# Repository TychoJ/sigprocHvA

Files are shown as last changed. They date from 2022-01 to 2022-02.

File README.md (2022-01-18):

# sigprocHvA
## Ned
Voor een opdracht van de HvA moet een filter ontworpen worden. Dit is voor het tweedejaars vak signaalverwerking toepassing. Dit filter moet zowel analoog als digitaal ontworpen worden en hier moet een verslag voor worden geschreven in het Nederlands.
___
## ENG
For a lab from the Amsterdam University of Applied there needed be a filter designed. This filter needed to be implemented analog as wel as digitally. Afterwords a report has to be written in dutch for this lab.
___

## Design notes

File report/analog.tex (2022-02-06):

\section{Analoog}
\subsection{De opdracht}
\begin{minipage}{0.45\textwidth}
	Maak een derde orde 0.5dB ripple chebyshev lowpass filter met een $F_C$ van 70Hz. In de doorlaat band 
	moet er met 10dB worden versterkt. Uit de tabel zijn de volgende gegevens te halen.

	\noindent
	Daarnaast moet het filter met de Sallen-key topologie worden gerealiseerd.
\end{minipage}
\hfill
\begin{minipage}{0.45\textwidth}
	\begin{itemize}
		\item In doorlaat +10dB versterking
		\item $\omega_{0_1}=1.0688$ 
		\item $\omega_{0_2}=0.6265$
		\item $\alpha = 0.5861$
		\item $Q=\frac{1}{\alpha}=1.7061$
	\end{itemize} % Gegevens komen uit tabel 8.30 van het boek linear circuit design
\end{minipage}

\subsection{Overdracht bepalen}
\begin{minipage}{0.40\textwidth}
	Door de waardes uit de tabel in te vullen in de standaard formule (zie formule \ref{eq:hs})
	komt daar formule \ref{eq:hsNum} uit.

	\noindent
	H(s) kan worden opgesplitst in een tweede orde deel en een eerste orde deel zie formule \ref{eq:hsSplit}.
	Het opsplitsen van $H(s)$ in $H(s)_1$ en $H(s)_2$ is noodzakelijk voor het goed ontwerpen van het analoge 
	filter.

	\noindent
	Het tweede orde deel heeft de overdracht die te zien is in formule \ref{eq:hs1} en de overdracht van
	het eerste orde	deel is te zien in formule \ref{eq:hs2}
\end{minipage}
\hfill
\begin{minipage}{0.60\textwidth}
	\begin{align}
		H(s)&=\frac{(\omega_{0_1}\cdot\omega_c)^2\cdot\omega_c\cdot\omega_{0_2}}{(s^2+ \alpha \cdot \omega_{0_1} \cdot \omega_c \cdot s + (\omega_{0_1}\cdot\omega_c)^2)\cdot (s + \omega_c \cdot \omega_{0_2})} \label{eq:hs} \\
		H(s)&=\frac{220\, 156.6429\,\cdot\, 275.0335}{(s^2+274.9999\cdot s+220\, 156.6429)(s+275.0335)} \label{eq:hsNum}\\
		H(s)&= H(s)_1 \cdot H(s)_2 \label{eq:hsSplit} \\ 
		H(s)&_1=\frac{(\omega_{0_1}\cdot\omega_c)^2}{s^2+ \alpha \cdot \omega_{0_1} \cdot \omega_c \cdot s + (\omega_{0_1}\cdot\omega_c)^2} \label{eq:hs1} \\ 
		H(s)&_2=\frac{\omega_c\cdot\omega_{0_2}}{s + \omega_c \cdot \omega_{0_2}} \label{eq:hs2} \\ 
	\end{align}
\end{minipage}
 
%$H(s)_1=\frac{220\, 156.6429}{s^2+274.9999s+220\, 156.6429}$
%$H(s)_2=\frac{275.0335}{s+275.0335}$

\subsection{Tweede orde/Sallen-key}
\begin{wrapfigure}[6]{l}{0.25 \textwidth}
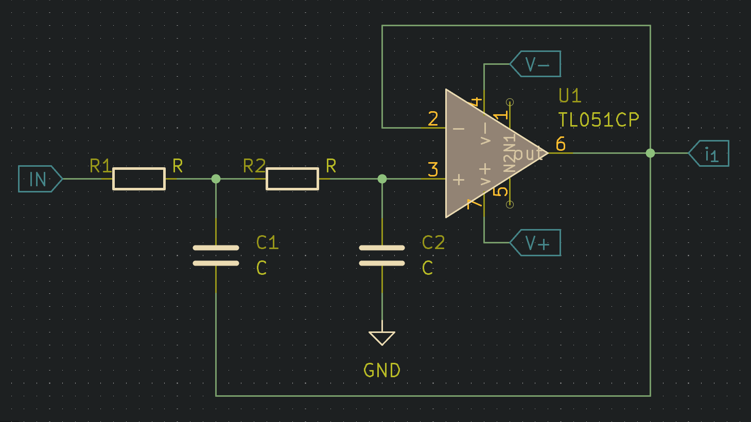
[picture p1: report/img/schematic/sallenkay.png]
	
	\caption{Sallen-key}
	\label{fig:sallenKey}
\end{wrapfigure}

\vphantom{-}\\
\begin{minipage}{0.37\textwidth}
	Het tweede orde deel van het derde orde filter wordt via de Sallen-key topologie gerealiseerd. In afbeelding \ref{fig:sallenKey} is te zien 
	hoe een laag doorlaat sallen-key filter er uit ziet.
\end{minipage}
\hfill
\begin{minipage}{0.37\textwidth}
	\begin{equation} \label{eq:c1}
		C_1=\frac{2Q}{\omega_c\omega_{0_1}R}
	\end{equation}
	\begin{equation} \label{eq:c2}
		C_2=\frac{1}{2Q\omega_c\omega_{0_1}R}
	\end{equation}
\end{minipage}
\vphantom{-}\\

\noindent
Als $R_1 = R_2$ kan $C_1$ berekend worden met formule \ref{eq:c1} en $C_2$ met formule \ref{eq:c2}.
Voor dit filter is gekozen om voor R $10k\Omega$ te kiezen. Waardoor $C_1=727nF$.

\noindent
727nF is alleen niet een waarde waarin condensatoren worden gemaakt. Door $C_1$ te veranderen naar 750nF 
kan er wel een condensator worden gekocht met de juiste waarde. 

\noindent
Door $C_2$ met formule \ref{eq:c2} uit te rekenen komt $C_2$ uit op een waarde van 62nF, deze waarde is wel direct 
te koop. 

\noindent
Beide waardes zitten alleen niet in de E6/12 reeks en zijn dus aanzienlijk duurder, 
hier gaat een afweging meespelen tussen de prijs van componenten en de kwaliteit van het filter.

\subsection{Eerste orde}
\begin{wrapfigure}[6]{l}{0.25\textwidth}
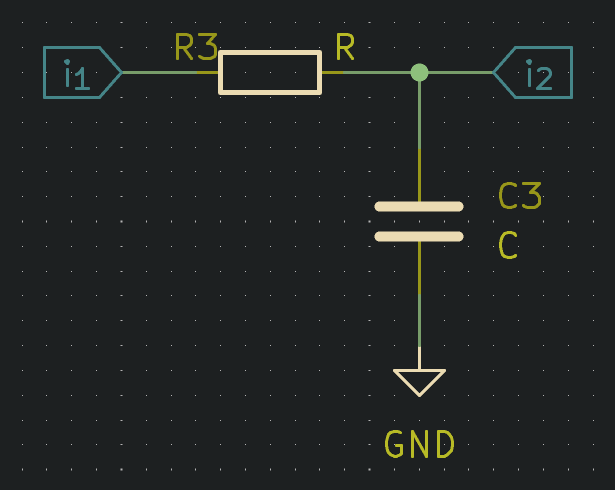
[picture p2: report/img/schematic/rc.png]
	
	\caption{Eerste orde lp filter}
	\label{fig:lp}
\end{wrapfigure}
\vphantom{-}\\
Een passief eerste orde laag doorlaat filter staat in figuur \ref{fig:lp}. Met formule \ref{eq:rc} is het mogelijk om de verschillende component waardes uit te rekenen 
voor het filter. Wij hebben $C_3=100nF$ gekozen waaruit formule \ref{eq:rcValR} volgt dat 
$R_3=5787\Omega$ dit moet worden afgerond op $5.6k\Omega$ omdat er geen weerstanden beschikbaar zijn met een waarde van $5787\Omega$.

\begin{flushright}
	\begin{minipage}{0.37\textwidth}
		\begin{equation} \label{eq:rc}
			\omega_c*\omega_{0_2}=\frac{1}{R_3C_3}
		\end{equation}
	\end{minipage}
	\begin{minipage}{0.37\textwidth}
		\begin{equation} \label{eq:rcValR}
			R_3=\frac{1}{\omega_c\omega_{0_2}C_3}
		\end{equation}
	\end{minipage}
\end{flushright}
\newpage

\subsection{LTspice}
Het filter dat in afbeelding \ref{fig:filterTotaal} is te zien is gesimuleerd in LTspice. De resultaten van de simulatie zijn te zien
in afbeelding \ref{fig:simRes}.
\begin{figure}[!htb]
	\begin{minipage}{0.45\textwidth}
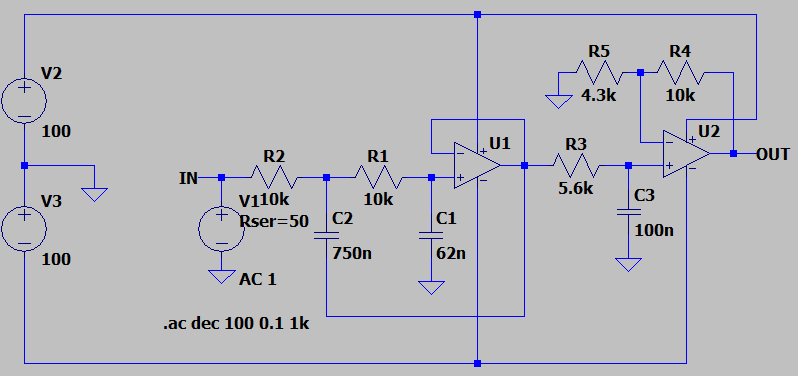
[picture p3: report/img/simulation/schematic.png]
		
		\caption{Eerste orde lp filter}
		\label{fig:filterTotaal}
	\end{minipage}
	\begin{minipage}{0.45\textwidth}
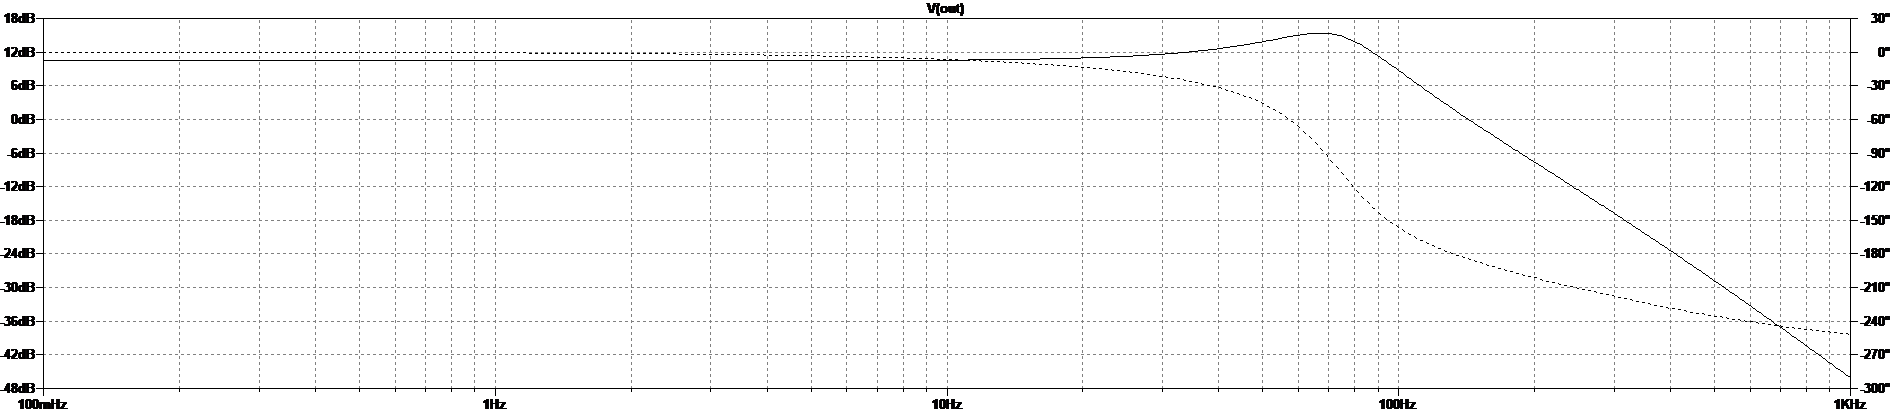
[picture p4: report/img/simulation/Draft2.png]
		
		\caption{LTspice simulatie}
		\label{fig:simRes}
	\end{minipage}
\end{figure}

\subsection{PCB}
	\begin{wrapfigure}[5]{r}{0.25\textwidth}
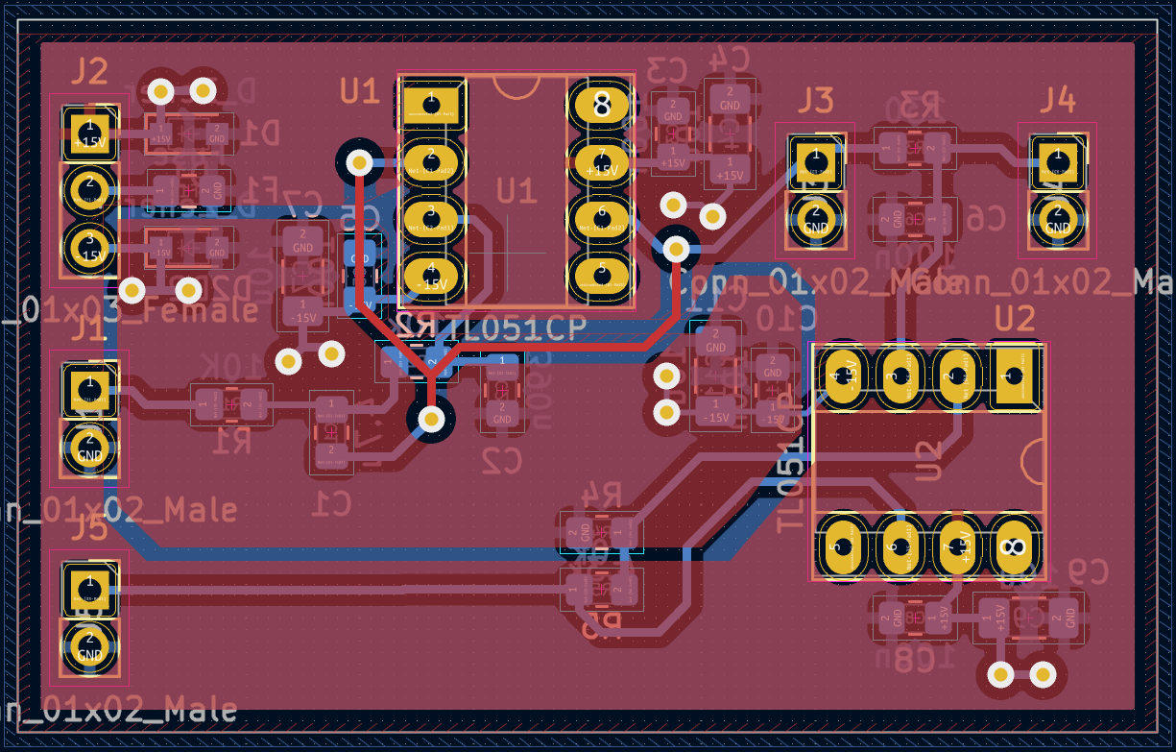
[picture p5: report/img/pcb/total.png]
		
		\caption{Layout}
		\label{fig:pcb:layout}
	\end{wrapfigure}
	Voor deze opdracht hebben wij een pcb ontworpen, op afbeelding \ref{fig:pcb:layout} is de layout te zien. Wij hebben er voor gekozen om een pcb te makenom de 
	parasitaire eigenschappen van onder anderen het breadboard tegen te gaan.

	\noindent
	Bij de layout zijn er nog wel een paar dingen die verbeterd zouden kunnen worden. Een voorbeeld is te zien in afbeelding \ref{fig:pcb:verbeter}
	en in afbeelding \ref{fig:pcb:verbeterde} is te zien hoe dit valt te verbeteren. 
	\begin{figure}[!htb]
		\begin{subfigure}[b]{0.33\textwidth}
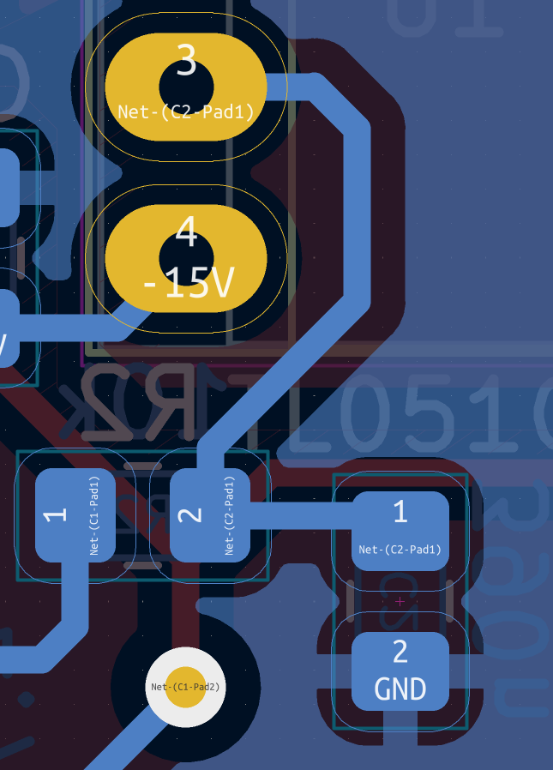
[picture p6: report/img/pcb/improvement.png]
			
			\caption{Dit kan worden verbeterd}
			\label{fig:pcb:verbeter}
		\end{subfigure}
		\begin{subfigure}[b]{0.33\textwidth}
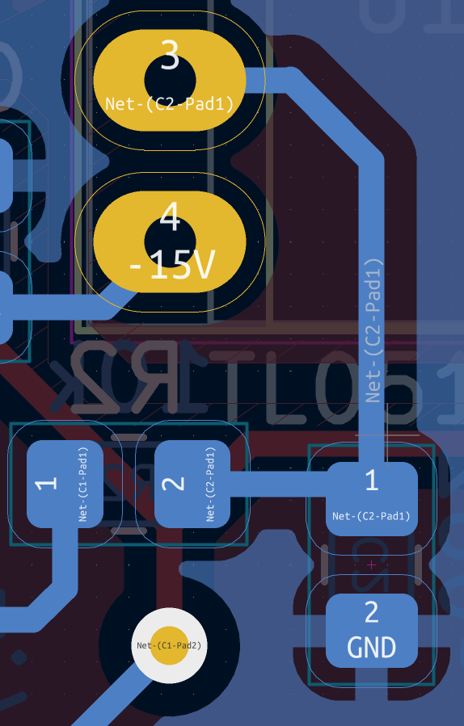
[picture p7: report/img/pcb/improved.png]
			
			\caption{Verbeterd}
			\label{fig:pcb:verbeterde}
		\end{subfigure}
		\caption{verbeter punt}
	\end{figure}

	\noindent
	Op afbeeldingen \ref{fig:pcb:3dBottom} en \ref{fig:pcb:3dTop} is een 3D render te zien van het gemaakte pcb. Bij het ontwerpen van dit pcb is 
	rekening gehouden met alle connectoren aan een kan van de print houden. Daarnaast zijn er nog een paar extra testpoints geplaatst om het debuggen
	van de schakeling makkelijker te maken als deze niet zou werken.
	\begin{figure}[!htb]
		\centering
		\begin{subfigure}[b]{0.45\textwidth}
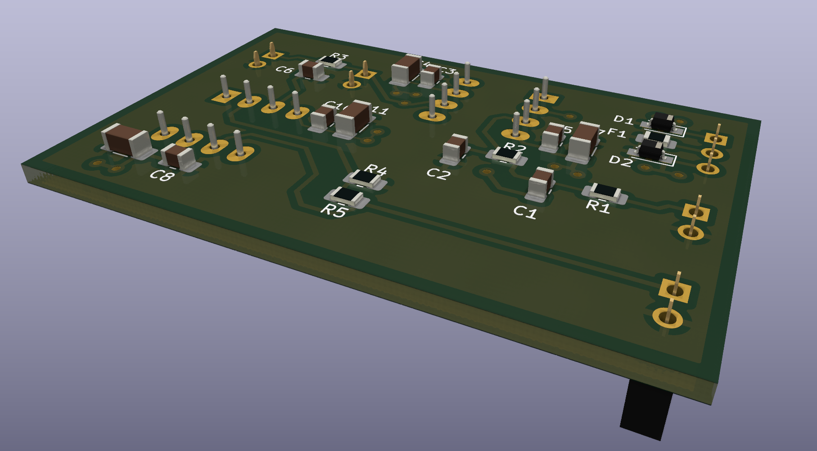
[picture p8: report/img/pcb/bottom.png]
			
			\caption{onderkant}
			\label{fig:pcb:3dBottom}
		\end{subfigure}
		\begin{subfigure}[b]{0.45\textwidth}
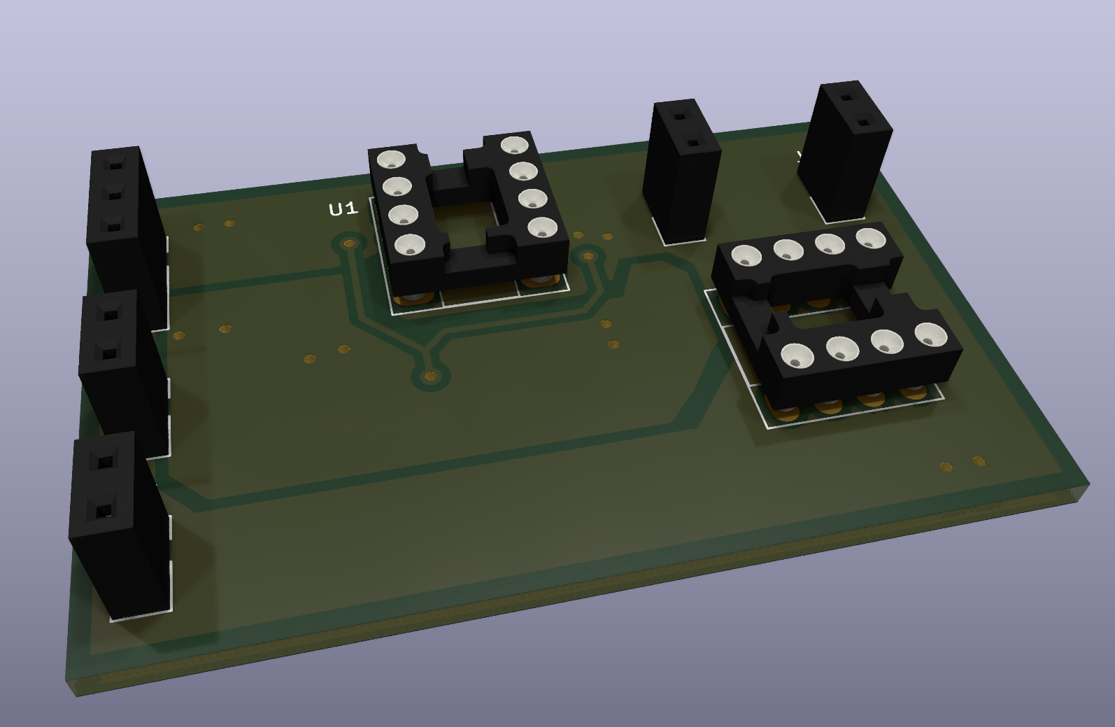
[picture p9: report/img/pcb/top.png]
			
			\caption{bovenkant}
			\label{fig:pcb:3dTop}
		\end{subfigure}
		\caption{3D renders}
	\end{figure}
	
\newpage

\subsection{Metingen}
\textbf{DISCLAIMER:} Tijdens het berekenen van het filter waren er wat reken fouten gemaakt waardoor het uiteindelijke ontwerp 
niet is opgebouwd met de correcte component waardes zoals ze in dit verslag staan. Het pcb is opgebouwd met de volgende waardes voor de componenten

\noindent
$R_1=R_2=10k\Omega$, $C_1=7.7uF$, $C_2=390nF$, $R_3=230\Omega$, $R_4=4.3k\Omega$ en $R_5=10k\Omega$
\\ 

\noindent
Bij alle metingen is er $\pm 10V$ geleverd ten opzichte van GND. Bij een ingangssignaal van 10Hz $1V_{PP}$ is op afbeelding \ref{fig:amp} te zien wat de output is.
Met een ingangssignaal van 70Hz $1V_{PP}$ is op afbeelding \ref{fig:atten} te zien wat de output is
\begin{figure}[!hbt]
	\begin{subfigure}{0.5\textwidth}
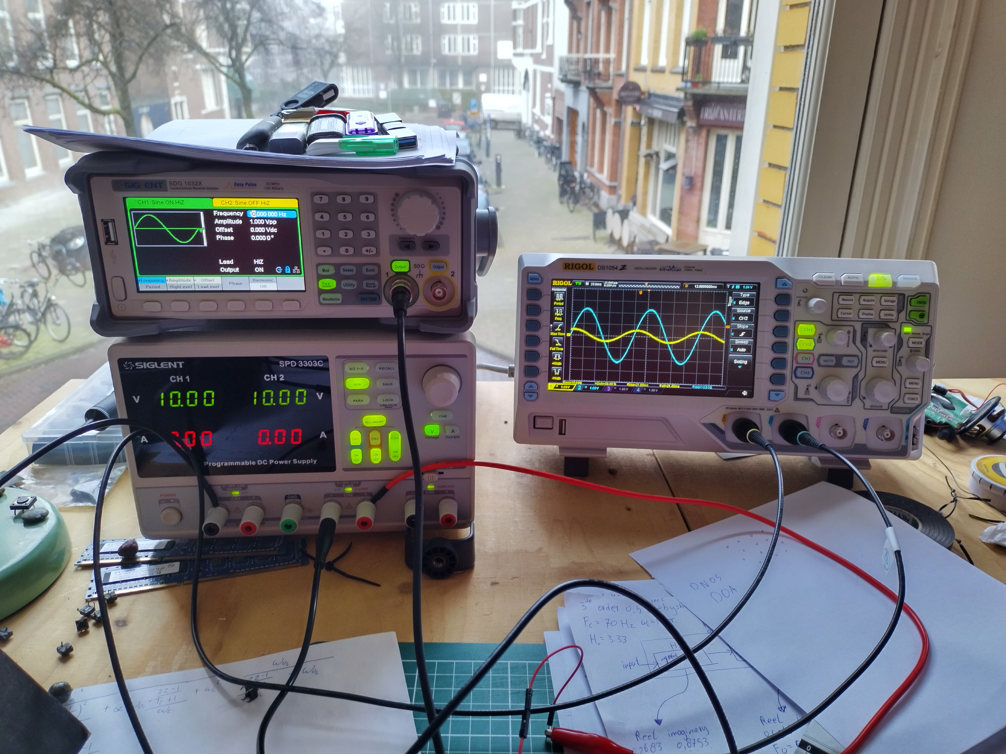
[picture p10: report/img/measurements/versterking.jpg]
		
		\caption{Versterking}
		\label{fig:amp}
	\end{subfigure}
	\begin{subfigure}{0.5\textwidth}
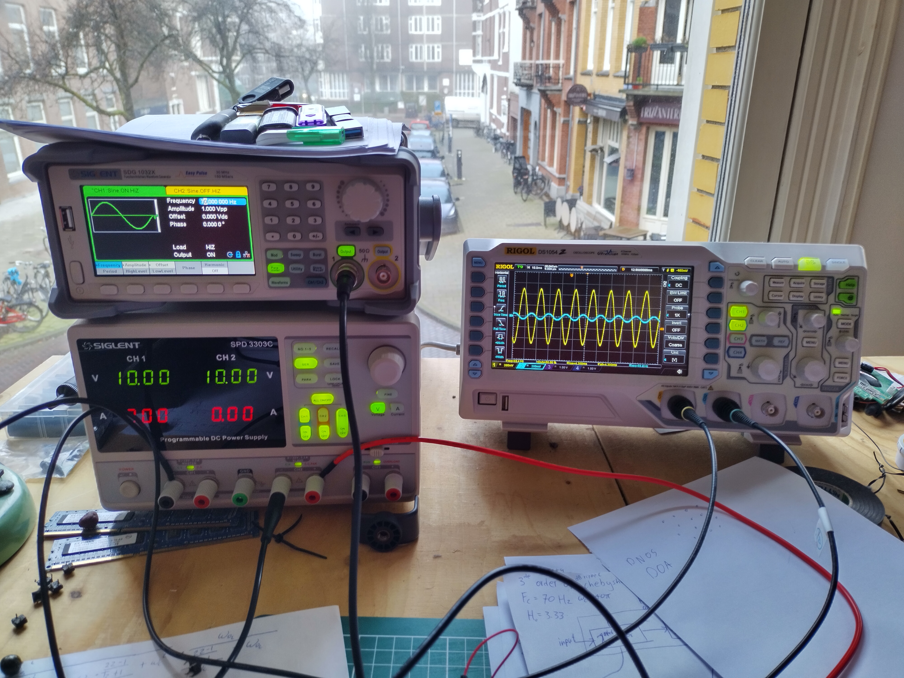
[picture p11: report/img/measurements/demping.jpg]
		
		\caption{Demping}
		\label{fig:atten}
	\end{subfigure}
	\caption{Meetingen met een oscilloscope}
\end{figure}

\noindent
Het is te zien dat in de doorlaat band het filter met ongeveer 10dB versterkt en in de stopband het signaal dempt. Waar exact het -3dB punt ligt is 
lichtelijk verschoven naar een lagere frequentie. Dit komt zoals in de disclaimer van dit stuk al staat er met verkeerde component waardes is gemeten.

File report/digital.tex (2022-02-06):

\section{Het digitale filter}

Met het MATLAB bestand voor een 1dB Chebychev filter hebben we een code geschreven voor het filter. 
Op het begin van de code worden alle waardes berekend in defines.
Deze waardes worden vervolgens gebruikt in de ISR van de ADC. De code is gebaseerd op de tekening in MATLAB.

\begin{figure}[!h]
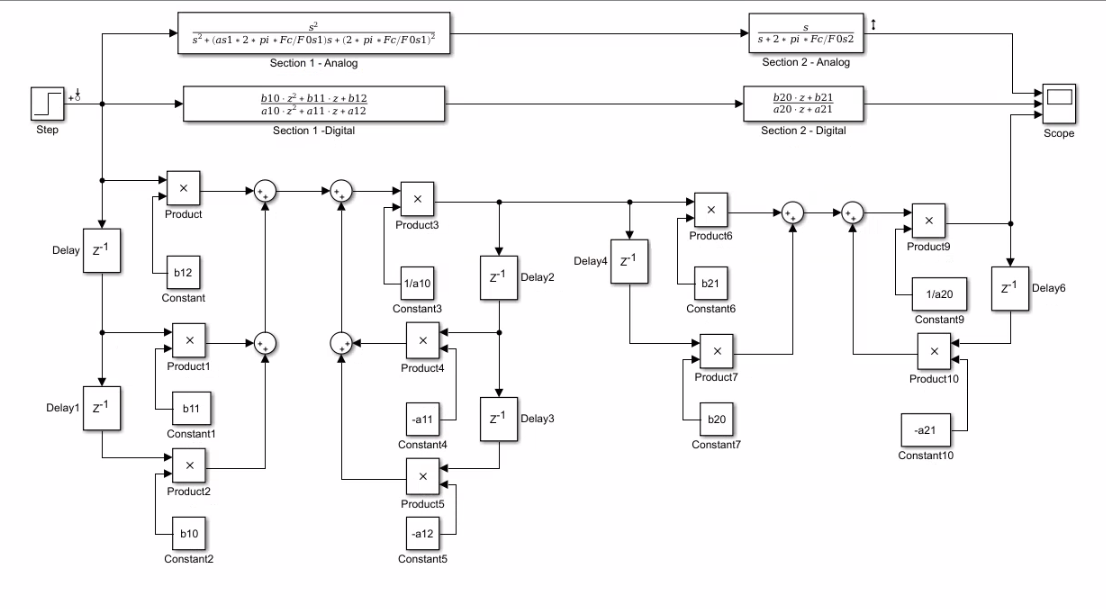
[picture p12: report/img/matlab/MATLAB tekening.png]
    
	\caption{Tekening in MATLAB}
	\label{fig:matlabDrawing}
\end{figure}

Het digitale filter is op dit moment niet functioneel.

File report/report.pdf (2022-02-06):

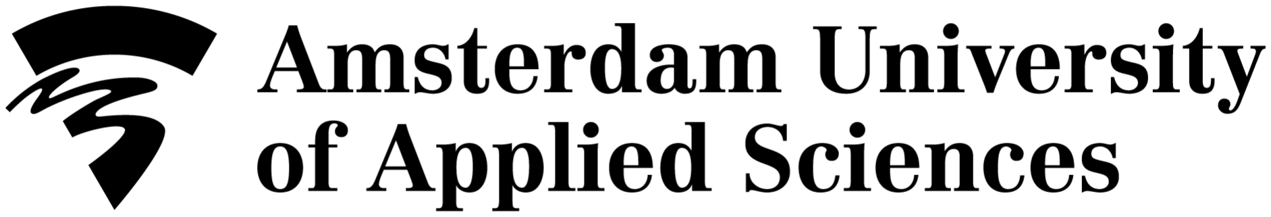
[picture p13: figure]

## Signaal verwerking toepassing

# derde orde 0.5dB chebyshev lp filter

Auteur(s): Tycho J¨obsis en Jochem Leijenhorst

Datum: 6 februari 2022 derde orde 0.5dB chebyshev lp filter

## Inhoudsopgave

1 Analoog | 2
INHOUDSOPGAVE | 1

derde orde 0.5dB chebyshev lp filter

## 1 Analoog

### 1.1 De opdracht

Maak een derde orde 0.5dB ripple chebyshev lowpass filter met een FC van 70Hz. In de doorlaat band moet er met 10dB worden versterkt. Uit de tabel zijn de volgende gegevens te halen.

| In doorlaat +10dB versterking
| ω01 = 1.0688
| ω02 = 0.6265
| α = 0.5861
| Q =
| 1 α = 1.7061

### 1.2 Overdracht bepalen

Door de waardes uit de tabel in te vullen in de standaard formule (zie formule 1) komt daar formule 2 uit.
H(s) kan worden opgesplitst in een tweede orde deel en een eerste orde deel zie formule 3. Het opsplitsen van H(s) in H(s)1 en H(s)2 is noodzakelijk voor het goed ontwerpen van het analoge filter.
Het tweede orde deel heeft de overdracht die te zien is in formule 4 en de overdracht van het eerste orde deel is te zien in formule 5
H(s) = | (ω01
- ωc)

2
- ωc · ω02
(s

2 + α · ω01
- ωc · s + (ω01
- ωc)
2) · (s + ωc · ω02
)

(1)

H(s) = | 220 156.6429 · 275.0335
(s
2 + 274.9999 · s + 220 156.6429)(s + 275.0335) | (2)
H(s) = H(s)1 · H(s)2 | (3)

H(s)1 =

(ω01

- ωc)

2
s

2 + α · ω01
- ωc · s + (ω01
- ωc)

2

(4)

H(s)2 =

ωc · ω02
s + ωc · ω02

(5)

(6)

### 1.3 Tweede orde/Sallen-key

Figuur 1: Sallen-key

Het tweede orde deel van het derde orde filter wordt via de Sallen-key topologie gerealiseerd. In afbeelding 1 is te zien hoe een laag doorlaat sallen-key filter er uit ziet.

C1 =

2Q
ωcω01R

(7)

C2 =

1
2Qωcω01R

(8)

Als R1 = R2 kan C1 berekend worden met formule 7 en C2 met formule 8. Voor dit filter is gekozen om voor R 10kΩ te kiezen. Waardoor C1 = 727nF.
727nF is alleen niet een waarde waarin condensatoren worden gemaakt. Door C1 te veranderen naar 750nF kan er wel een condensator worden gekocht met de juiste waarde.
Door C2 met formule 8 uit te rekenen komt C2 uit op een waarde van 62nF, deze waarde is wel direct te koop.
Beide waardes zitten alleen niet in de E6/12 reeks en zijn dus aanzienlijk duurder, hier gaat een afweging meespelen tussen de prijs van componenten en de kwaliteit van het filter.

### 1.4 Eerste orde

### 1.5 LTspice

### 1.6 Metingen

2

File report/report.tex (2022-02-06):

\documentclass[10pt, a4paper]{article}

\usepackage[dutch]{babel} 
\usepackage{hvaTemplate}
\usepackage{wrapfig}
\usepackage{caption}
\usepackage{subcaption}

\setAuthor{Tycho Jöbsis en Jochem Leijenhorst}
\extraInfo{Signaal verwerking toepassing}
\setTitle{derde orde 0.5dB chebyshev lp filter}

\graphicspath{ {img/} }

\begin{document}
\makeTitlepage
\newpage
\tableofcontents
\newpage
\include{analog.tex}
\include{digital.tex}
\end{document}

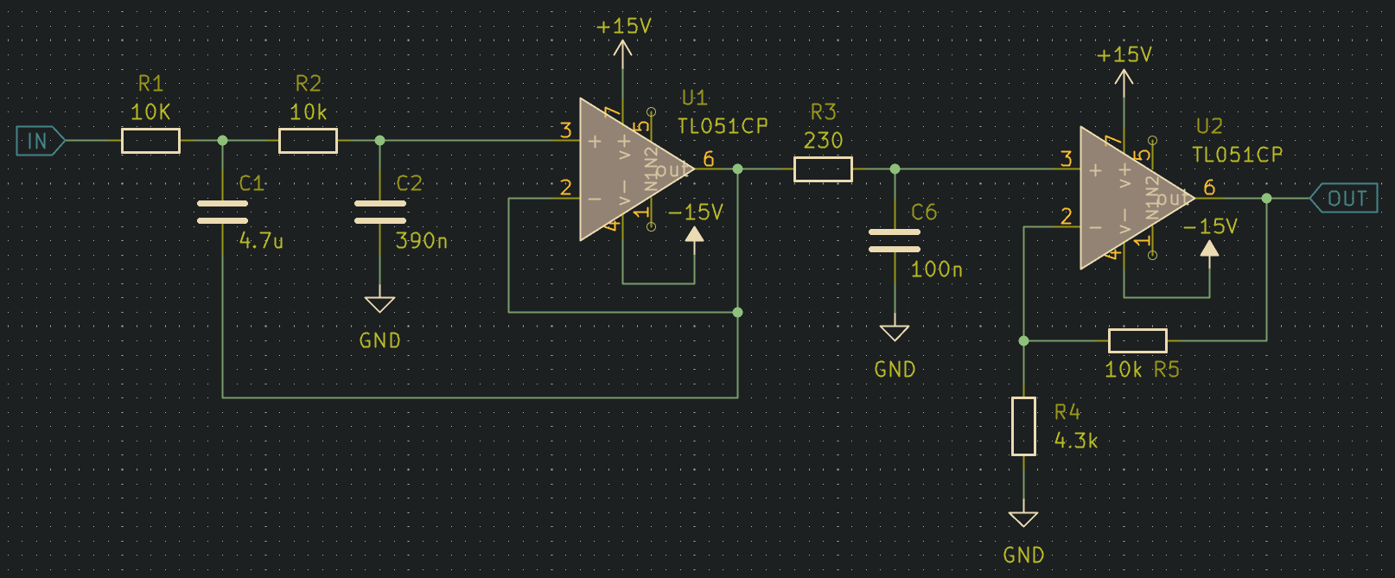
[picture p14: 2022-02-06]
report/img/schematic/complete.png

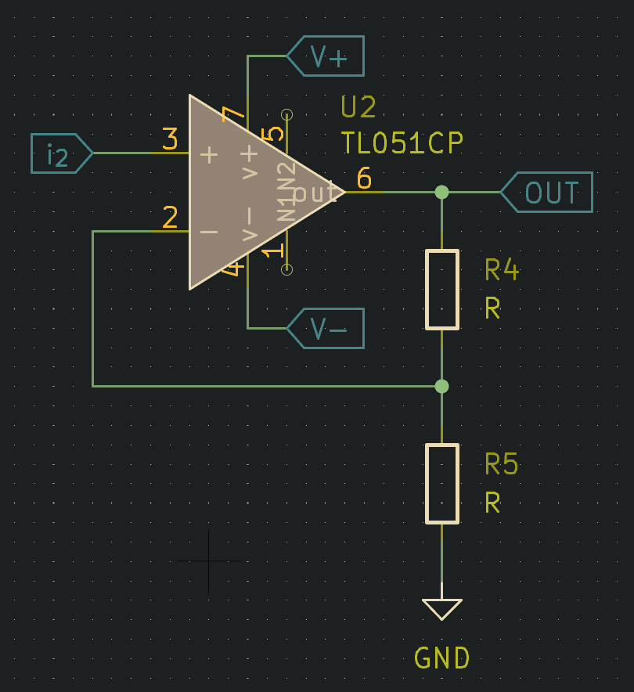
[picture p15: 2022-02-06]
report/img/schematic/nonInOpamp.png

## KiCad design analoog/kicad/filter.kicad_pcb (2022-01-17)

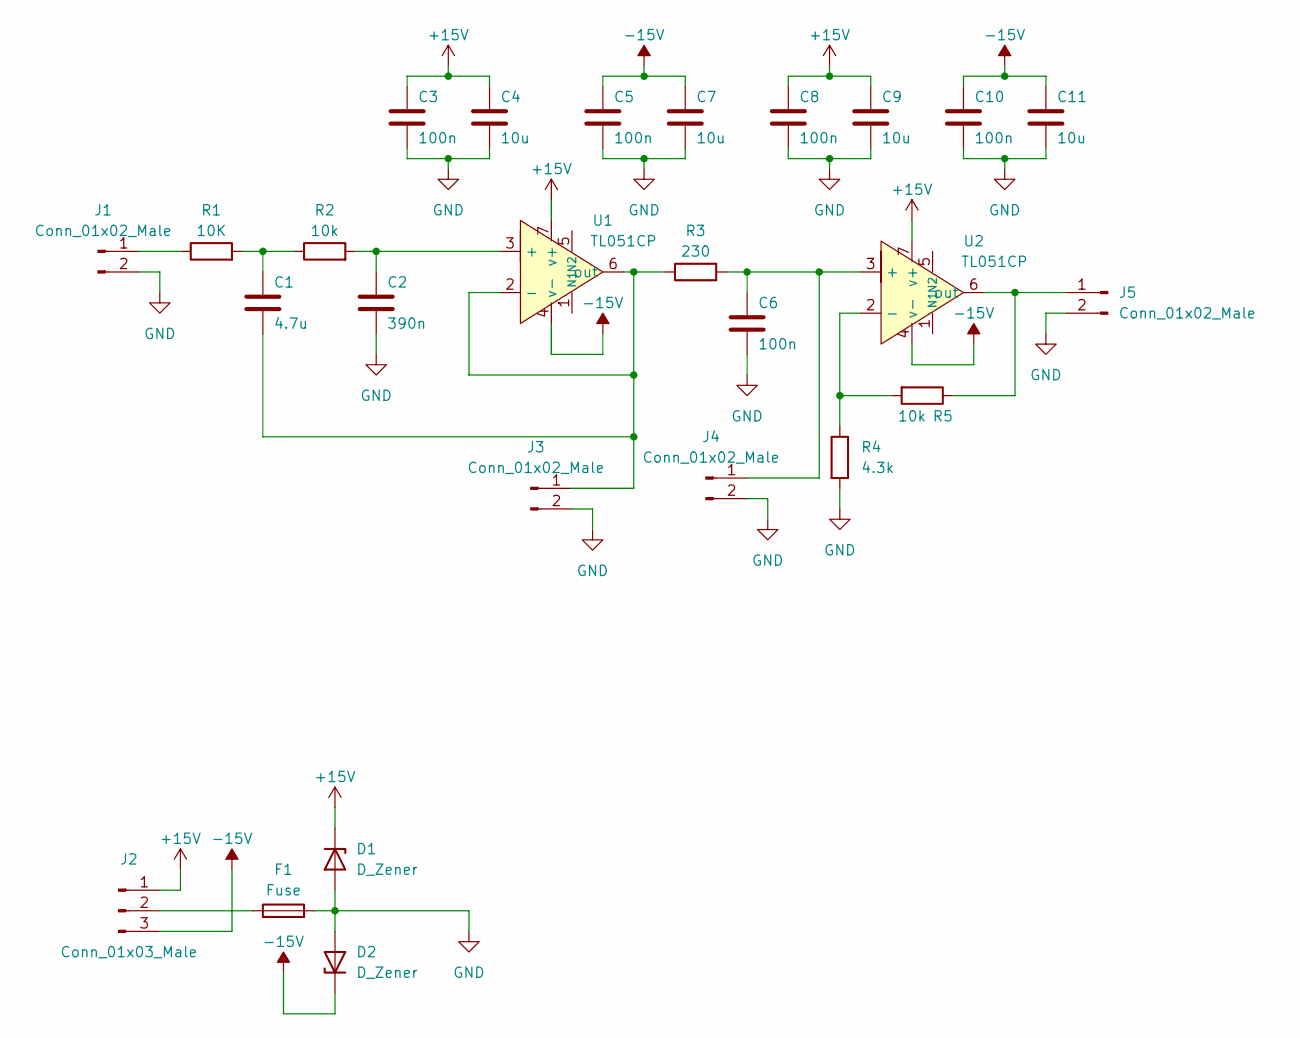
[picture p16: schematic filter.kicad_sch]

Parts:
C1: 4.7u; C_0805_2012Metric_Pad1.18x1.45mm_HandSolder
C2: 390n; C_0805_2012Metric_Pad1.18x1.45mm_HandSolder
C3, C5, C6, C8, C10: 100n; C_0805_2012Metric_Pad1.18x1.45mm_HandSolder
C4, C7, C9, C11: 10u; C_1206_3216Metric_Pad1.33x1.80mm_HandSolder
D1, D2: D_Zener; D_SOD-323_HandSoldering
F1: Fuse; Fuse_0805_2012Metric_Pad1.15x1.40mm_HandSolder
J1, J3, J4, J5: Conn_01x02_Male; PinSocket_1x02_P2.54mm_Vertical
J2: Conn_01x03_Male; PinSocket_1x03_P2.54mm_Vertical
R1: 10K; R_0805_2012Metric_Pad1.20x1.40mm_HandSolder
R2, R5: 10k; R_0805_2012Metric_Pad1.20x1.40mm_HandSolder
R3: 230; R_0805_2012Metric_Pad1.20x1.40mm_HandSolder
R4: 4.3k; R_0805_2012Metric_Pad1.20x1.40mm_HandSolder
U1, U2: TL051CP; DIP-8_W7.62mm_Socket_LongPads

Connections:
+15V: C3.1, C4.1, C8.1, C9.1, D1.1 (K), J2.1, U1.7 (v+), U2.7 (v+)
-15V: C5.1, C7.1, C10.1, C11.1, D2.1 (K), J2.3, U1.4 (v-), U2.4 (v-)
GND: C2.2, C3.2, C4.2, C5.2, C6.2, C7.2, C8.2, C9.2, C10.2, C11.2, D1.2 (A), D2.2 (A), F1.2, J1.2, J3.2, J4.2, J5.2, R4.2
unnamed: C1.1, R1.2, R2.1
unnamed: C1.2, J3.1, R3.1, U1.2 (-), U1.6 (out)
unnamed: C2.1, R2.2, U1.3 (+)
unnamed: C6.1, J4.1, R3.2, U2.3 (+)
unnamed: F1.1, J2.2
unnamed: J1.1, R1.1
unnamed: J5.1, R5.1, U2.6 (out)
unnamed: R4.1, R5.2, U2.2 (-)

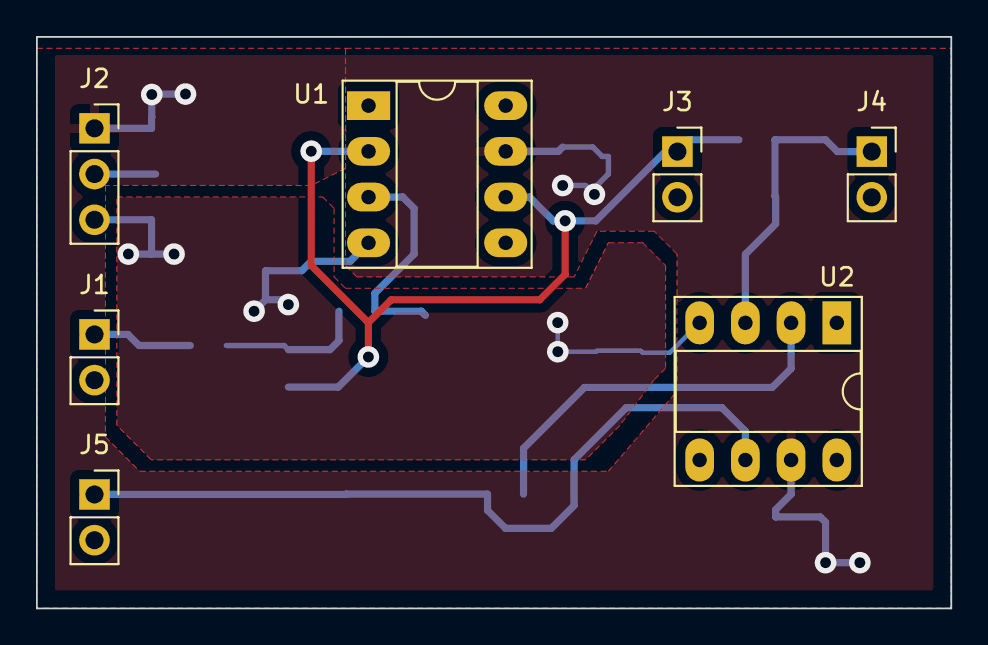
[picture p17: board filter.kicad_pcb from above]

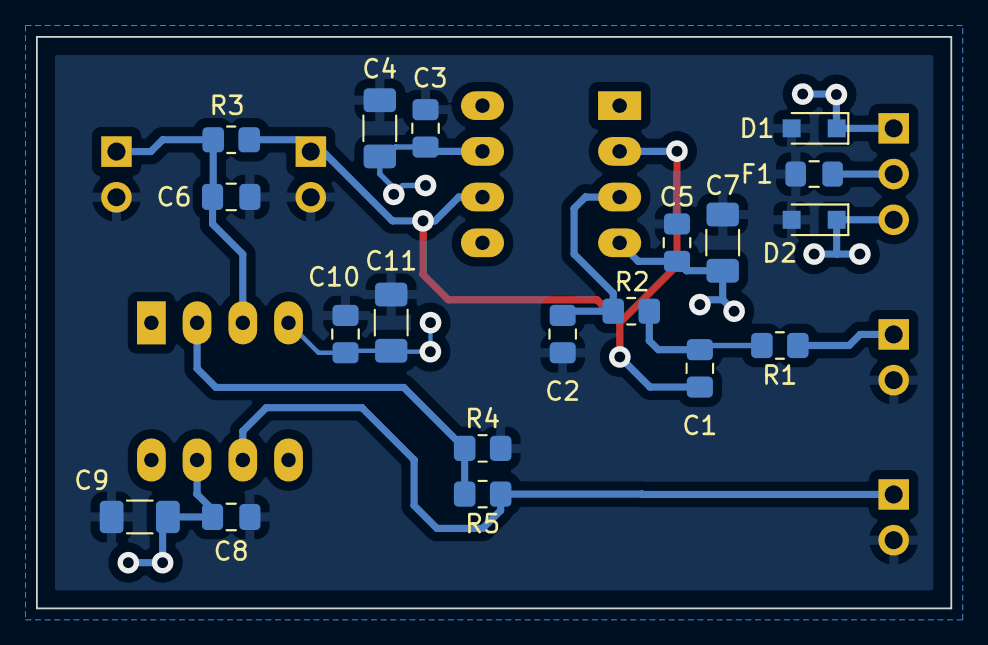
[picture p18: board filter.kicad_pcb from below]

Board: 2 copper layers, 50.8 x 31.8 mm, 26 parts (19 on the bottom side), 11 nets.

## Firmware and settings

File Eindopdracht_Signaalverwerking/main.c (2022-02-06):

#define F_CPU 32000000UL
#include <avr/io.h>
#include <avr/interrupt.h>
#include <util/delay.h>
#include <string.h>
#include <math.h>

#include "clock.h"

// Dit programma leest d.m.v de ADC de spanning op PIN A2.
// Dit is de input van je digitale filter. Dit filter moet je zelf bouwen.
// De output van je digitale filter wordt d.m.v. de DAC op PIN A10 gezet.
// De samplefrequentie van deze routine wordt bepaald door een timer interrupt.


//ADC_voltage:
#define MAX_VALUE_ADC   2047                               // only 11 bits are used
#define VCC			(float) 3.3
#define VREF		(float) VCC / 1.6

#define N		8UL
#define F_CLK	1000UL
#define TC_PER	(F_CPU / ((N * F_CLK)) - 1)

//DAC
#define MAX_VALUE_DAC 4095
#define CAL_DAC 1.000  // Calibratiewaarde DAC

#define ADC2DAC (float)(VREF * MAX_VALUE_DAC * CAL_DAC) / ((MAX_VALUE_ADC + 1) * VCC)

#define FIR_LAYERS 19

#define Fc		(double) 70
#define F0s1	(double) 1.0688
#define F0s2	(double) 0.6265
#define as1		(double) 0.5861

#define T		(double) 0.001
#define T2		(double) T * T
#define Td1		(double) 1 / T
#define Td12	(double) 1 / (T * T)
 
#define wcs1	(double) 2 * Fc * M_PI / F0s1
#define wcs2	(double) 2 * Fc * M_PI / F0s2

#define a10		(double) 4 * Td12 + as1 * wcs1 * 2 * Td1 + wcs1*wcs1
#define a11		(double) 2 * wcs1 * wcs1 - 8 * Td12
#define a12		(double) 4 * Td12 - as1 * wcs1 * 2 * Td1 + wcs1*wcs1
#define a20		(double) 2 * Td1 + wcs2
#define a20d1	1 / a20
#define a21		(double) wcs2 - 2 * Td1

#define b10		(double) 4 * Td12
#define b11		(double) -8 * Td12
#define b12		(double) 4 * Td12
#define b20		(double) -2 * Td1
#define b21		(double) 2 * Td1

float b1[] = {b10, b11, b12};
float b2[] = {b20, b21};

float a1[] = {a10, a11, a12};
float a2[] = {a20, a21};
	

inline int8_t keepIn3(int8_t value) {
	return value + 3 * (value < 0);
}

void init_timer(void){
	TCE0.CTRLB     = TC_WGMODE_NORMAL_gc;	// Normal mode
	TCE0.CTRLA     = TC_CLKSEL_DIV8_gc;	// prescaling 8 (N = 64)
	//TCE0.INTCTRLA  = TC_OVFINTLVL_MED_gc;	// enable overflow interrupt medium level
	TCE0.PER       = TC_PER;	//(62499/2)*0.002;			// sampletijd ( (62499/2) = 1 sample/seconde).
}

void init_adc(void){
	PORTA.DIRCLR		= PIN2_bm|PIN3_bm;
	ADCA.CH0.MUXCTRL	= ADC_CH_MUXPOS_PIN2_gc |	// PA2 (PIN A2) to + channel 0
	ADC_CH_MUXNEG_GND_MODE3_gc;						// GND to - channel 0
	ADCA.CH0.CTRL	= ADC_CH_INPUTMODE_DIFF_gc;		// channel 0 differential mode
	ADCA.REFCTRL	= ADC_REFSEL_INTVCC_gc;
	ADCA.CTRLB		= ADC_RESOLUTION_12BIT_gc |
	ADC_CONMODE_bm;				// signed conversion
	ADCA.PRESCALER	= ADC_PRESCALER_DIV16_gc;
	ADCA.EVCTRL		= ADC_SWEEP_0_gc |			// sweep channel 0
	ADC_EVSEL_0123_gc |		// select event channel 0, 1, 2, 3
	ADC_EVACT_CH0_gc;			// event system triggers channel 0
	EVSYS.CH0MUX	= EVSYS_CHMUX_TCE0_OVF_gc;	// Timer overflow E0 event
	ADCA.CH0.INTCTRL	= ADC_CH_INTMODE_COMPLETE_gc | ADC_CH_INTLVL_LO_gc; // enable ADCA CH0 interrupt when conversion is complete
	ADCA.CTRLA		= ADC_ENABLE_bm;
}

void init_dac(void){
	DACB.CTRLC = DAC_REFSEL_AVCC_gc;
	DACB.CTRLB = DAC_CHSEL_SINGLE_gc;
	DACB.CTRLA = DAC_CH0EN_bm | DAC_ENABLE_bm;
}


//ISR(TCE0_OVF_vect){				//TIMER Interupt
// 	int16_t  voltage ;		// contains read in voltage (mVolts)
//PORTC.OUTTGL = PIN0_bm;	//Toggle the LED

//ADCA.CH0.CTRL |= ADC_CH_START_bm; // start conversion
// 	voltage = (double) res * 1000 * VREF / (MAX_VALUE_ADC + 1);					// Measured voltage in Volts.
// 	if (voltage < 0) voltage = 0;
//}


ISR(ADCA_CH0_vect){
	PORTC.OUTTGL = PIN0_bm;	//Toggle the LED
	
	static double x0[3] = {0,0,0};
	static double x1[3] = {0,0,0};
	static double x2[2] = {1,1};
	static double y[2] = {1,1};

	static int8_t xIndex = 0;
	static int8_t yIndex = 0; //Wordt ook gebruikt voor x2.
	
	
	//	<Jochem code>
	
	x0[xIndex] = (double)ADCA.CH0.RES;
	x1[xIndex] = 0;
	
	// Eerste deel
	for(uint8_t i = 1; i < 3; i++) { 
		x1[xIndex] += b1[2 - i] * x0[keepIn3(xIndex - i)];
		// Het meest recente monster moet vermenigvuldigt worden met b12, daarna b11, dan b10
	}
	
	for (uint8_t i = 1; i < 3; i++) {
		x1[xIndex] += -a1[i] * x1[keepIn3(xIndex - i)];
	}
	
	x1[xIndex] /= a10;
	
	
	// Tweede deel
	// Dit kan modulairder maar dan wordt het minder snel.
	// Modulairder is een mooi woord.
	
	x2[yIndex] = b21 * x1[xIndex] + b20 * x2[!xIndex];
	y[yIndex]  = (x2[yIndex] - a21 * y[yIndex]) * a20d1;// + -a21 * y[!yIndex]); //* a20d1;

	int16_t out = (int16_t)(y[yIndex]) * ADC2DAC;


	// NaN catcher
// 	if(y[0] != y[0]) y[0] = 0;
// 	if(y[1] != y[1]) y[1] = 0;
	
	xIndex = (xIndex + 1) % 3;
	yIndex = !yIndex; 
	// Hij moet gewoon wisselen tussen 1 en 0 dus dan is dit sneller
	
	//	</Jochem code>
	
// 	printOut = ADC2DAC;
	DACB.CH0DATA = out;			//write &USBDataIn to DAC (PIN A10)
	while (!DACB.STATUS & DAC_CH0DRE_bm);
	
}


int main(void){
	PORTC.DIRSET = PIN0_bm;	// the LED (bit 0 on port C) is set as output.
	PORTB.DIRSET = PIN2_bm;
	PORTF.DIRSET = PIN0_bm | PIN1_bm;

	init_clock();
	init_timer();			// init timer
	init_dac();				// init DAC
	init_adc();				// init ADC
// 	init_stream(F_CPU);
		
	PMIC.CTRL     |= PMIC_LOLVLEN_bm | PMIC_MEDLVLEN_bm;		// set low and medium level interrupts
	sei();					//Enable interrupts
// 	printf("\n\nStart met poezen aaien\n");
// 	printf("%lf\t%lf\n%lf\t%lf\t%lf\n%lf\t%lf\n%lf\t%lf\t%lf\n%lf\t%lf\n", T, Td12, a10, a11, a12, a20, a21, b10, b11, b12, b20, b21);
	
	PORTF.OUTSET = PIN1_bm;
	_delay_ms(1000);
	PORTF.OUTCLR = PIN1_bm;
	
	while (1) {
		asm volatile ("nop");
	}
}

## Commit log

2022-01-17 changed file structure
    [filter.kicad_pcb, filter.kicad_sch]
2022-01-18 added LTspice files
    [filter.kicad_pcb, filter.kicad_sch]
2022-02-06 Filter code gemaakt en gecompileert. Nog niet getest.
2022-02-06 sample rate fix
